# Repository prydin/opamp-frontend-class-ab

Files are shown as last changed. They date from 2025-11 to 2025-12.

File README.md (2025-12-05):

# The Teamwork Amplifier - 50W (8 ohm) Low Distortion Class AB Audio Amplifier

## Background
This is a team effort that started as a conversation on diyaudio.com. Member stigigemla and I were bouncing ideas back and forth and member steveu took one my design
attempts and came up with an overhauled and much improved version. I just added some extra features like overcurrent protecton and VI limiters and slapped together a PCB. 
I built it as an experiment.

The result is a fast amplifier (>80V/us slew rate) with low distortion (0.00045% meadured @ 1kHz/1W/8ohm resistive load). It's undergone some preliminary measurements
and looks quite promising. 

## Disclaimer
The schematic and PCB layout are free to use as you please, but bear in mind that it's only undergone a bare minimum of testing! Build at your own risk!

## Credits and acknowledgements
There were several people involved in the creation of this design. If you're not mentioned and feel you should be, just add your name and issue a PR! 

## Schematic
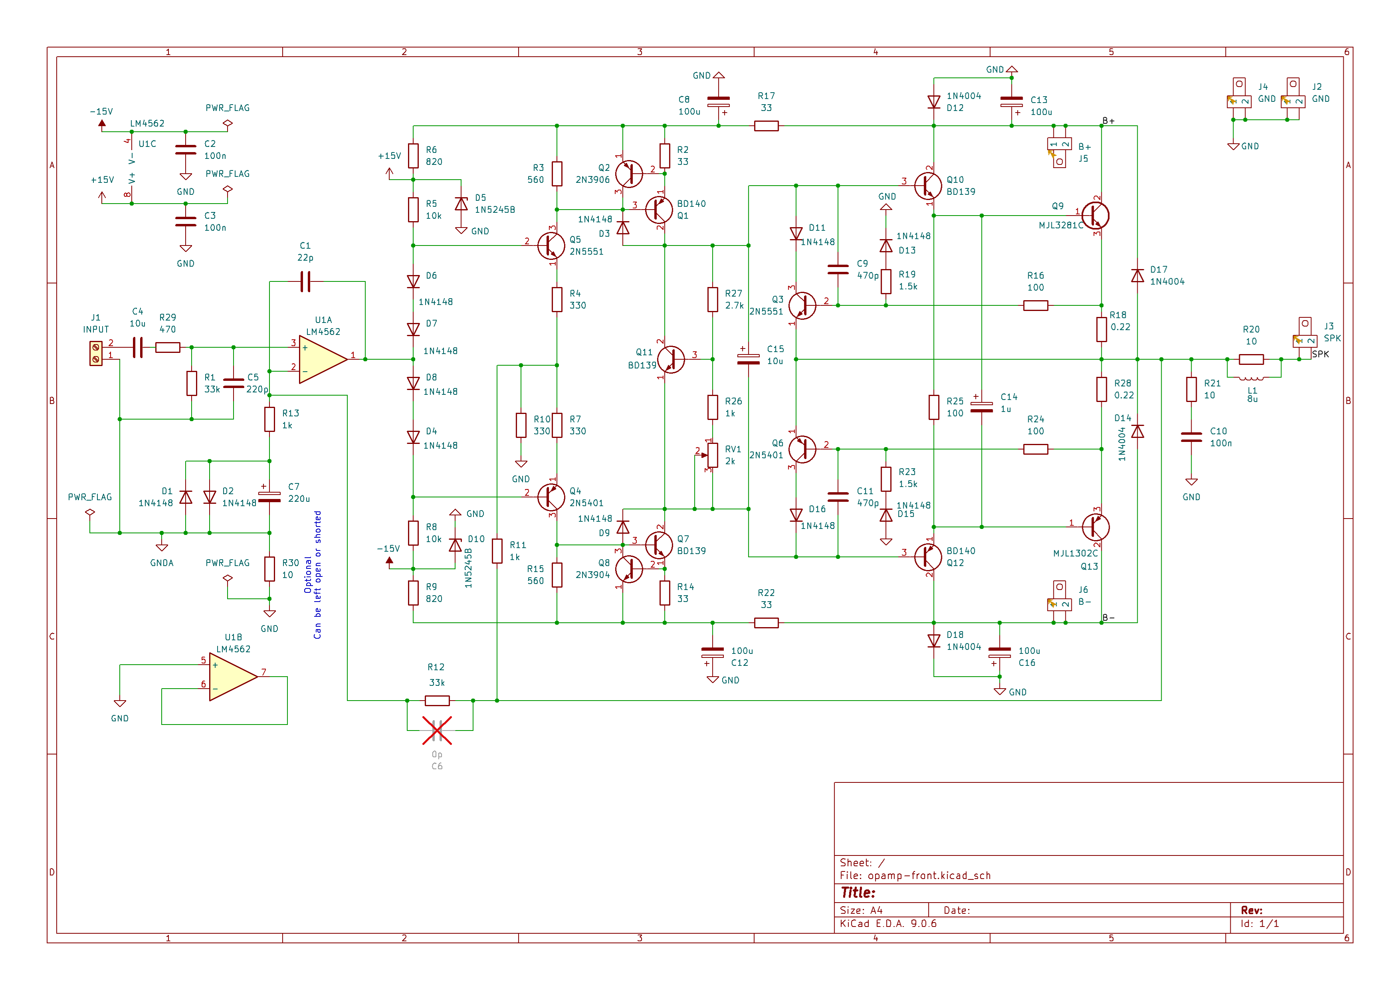
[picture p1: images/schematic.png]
Schematic


## PCB 3D rendering
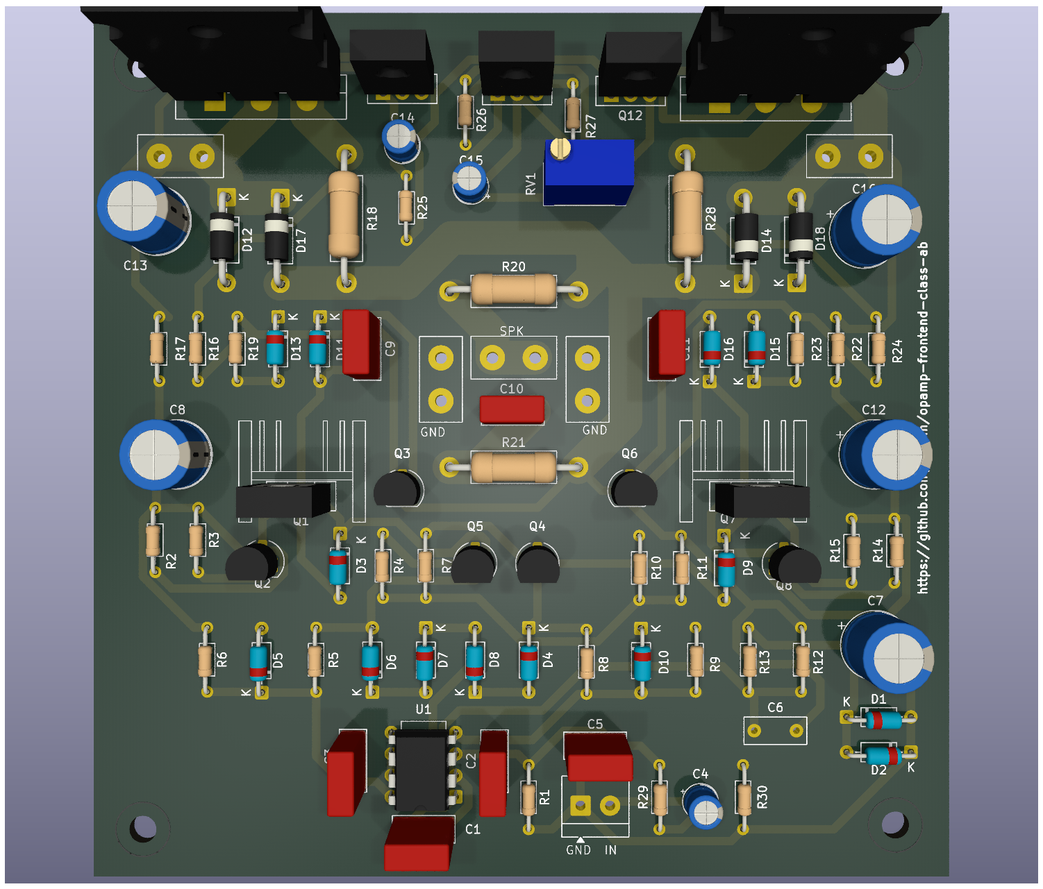
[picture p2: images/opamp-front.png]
PCB


## Measurements
- THD: 0.00045% @ 1W/1kHz/150mA bias
- SNR: >95dB
- Bandwidth: 10Hz-500kHz
- Slew rate: >80V/us

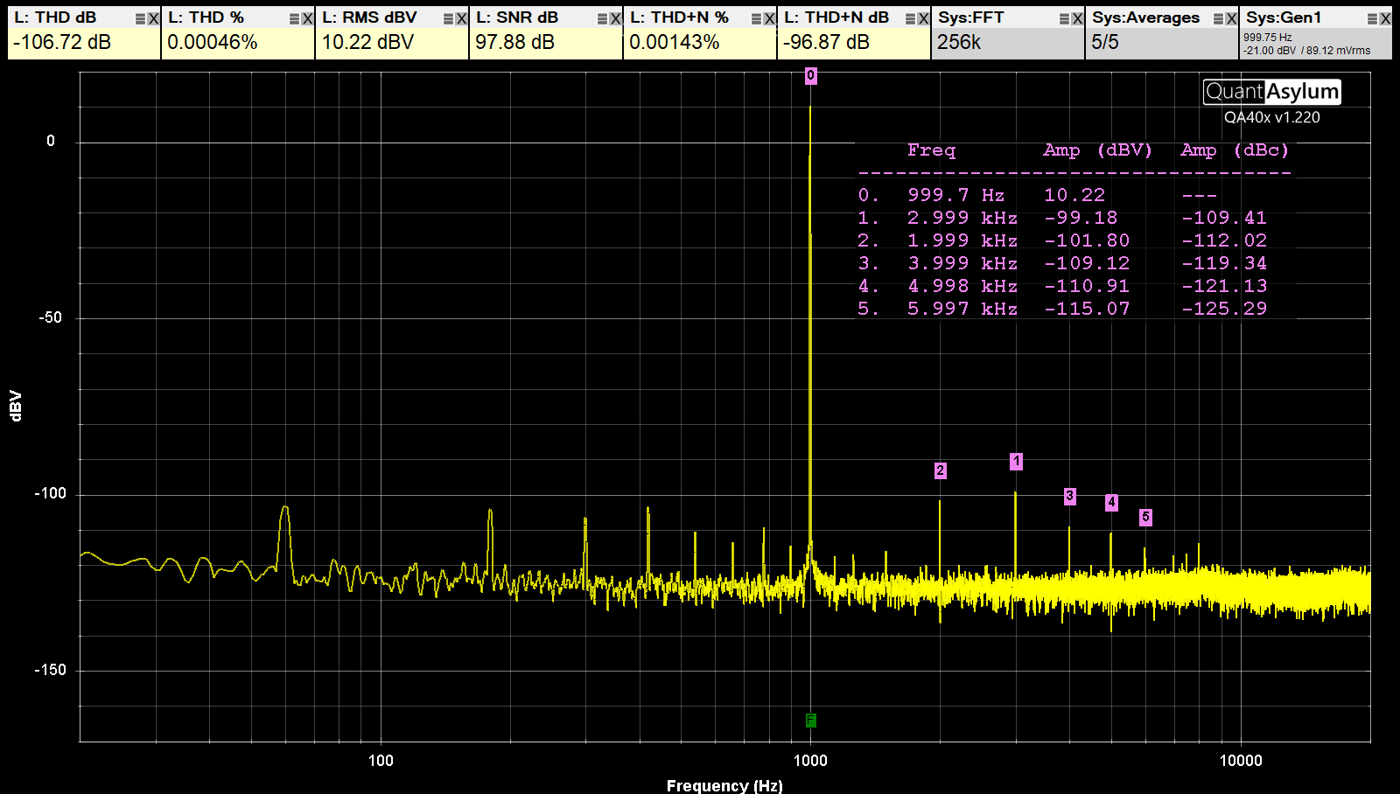
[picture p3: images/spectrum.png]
Spectrum


## Subjective listening impression
After a few hours of listening, I have to say I'm pleased with the sound quality. It character is very crisp and clean. Drum beats and cymbals feel very snappy. 
If you're looking for an amplifierthat colors the sound, this won't be your cup of tea. But so far I would say it does a great job at cleanly reproducing the source material. 

## Construction
I found an old, broken AudioSource Amp 100 on eBay for close to no money and reused the chassis, pots, connectors and transformer. The boards ended up fitting perfectly if
I moved the heatsink maybe 3mm back and removed the input switching board (which I didn't want or need anyway). It ended up being a neat and inexpensive build
that looks sleek and clean. 

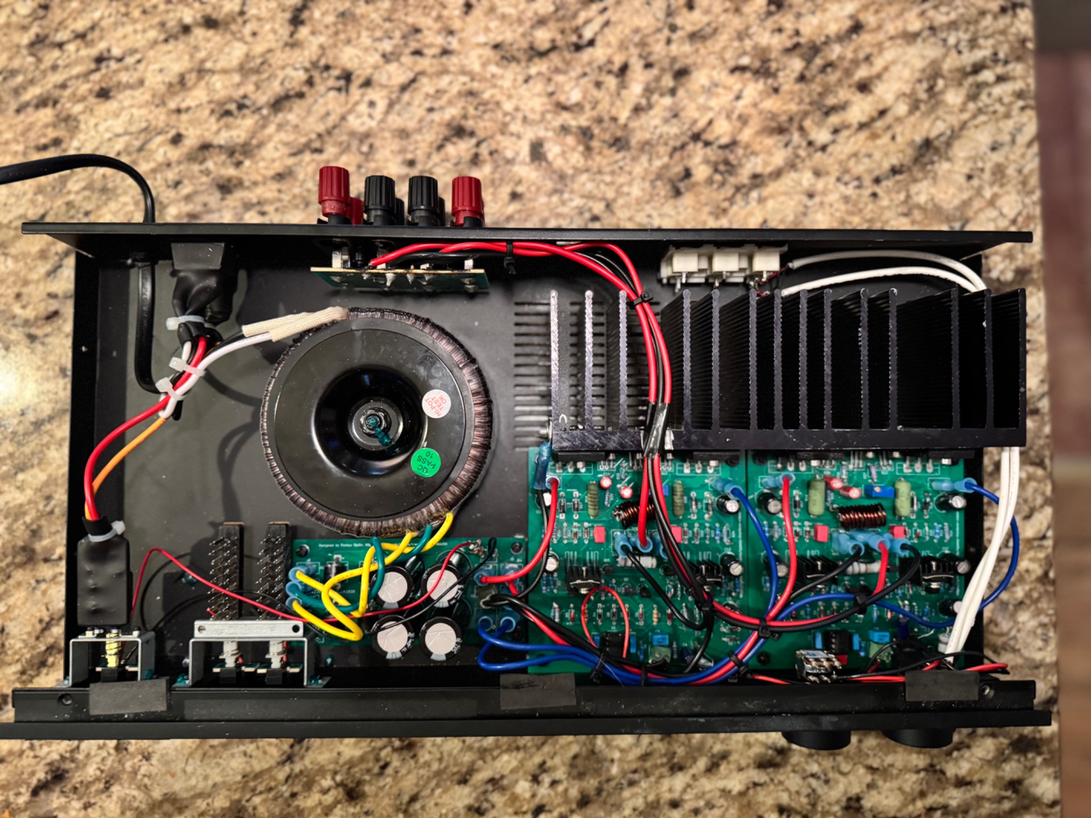
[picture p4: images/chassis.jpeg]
Build


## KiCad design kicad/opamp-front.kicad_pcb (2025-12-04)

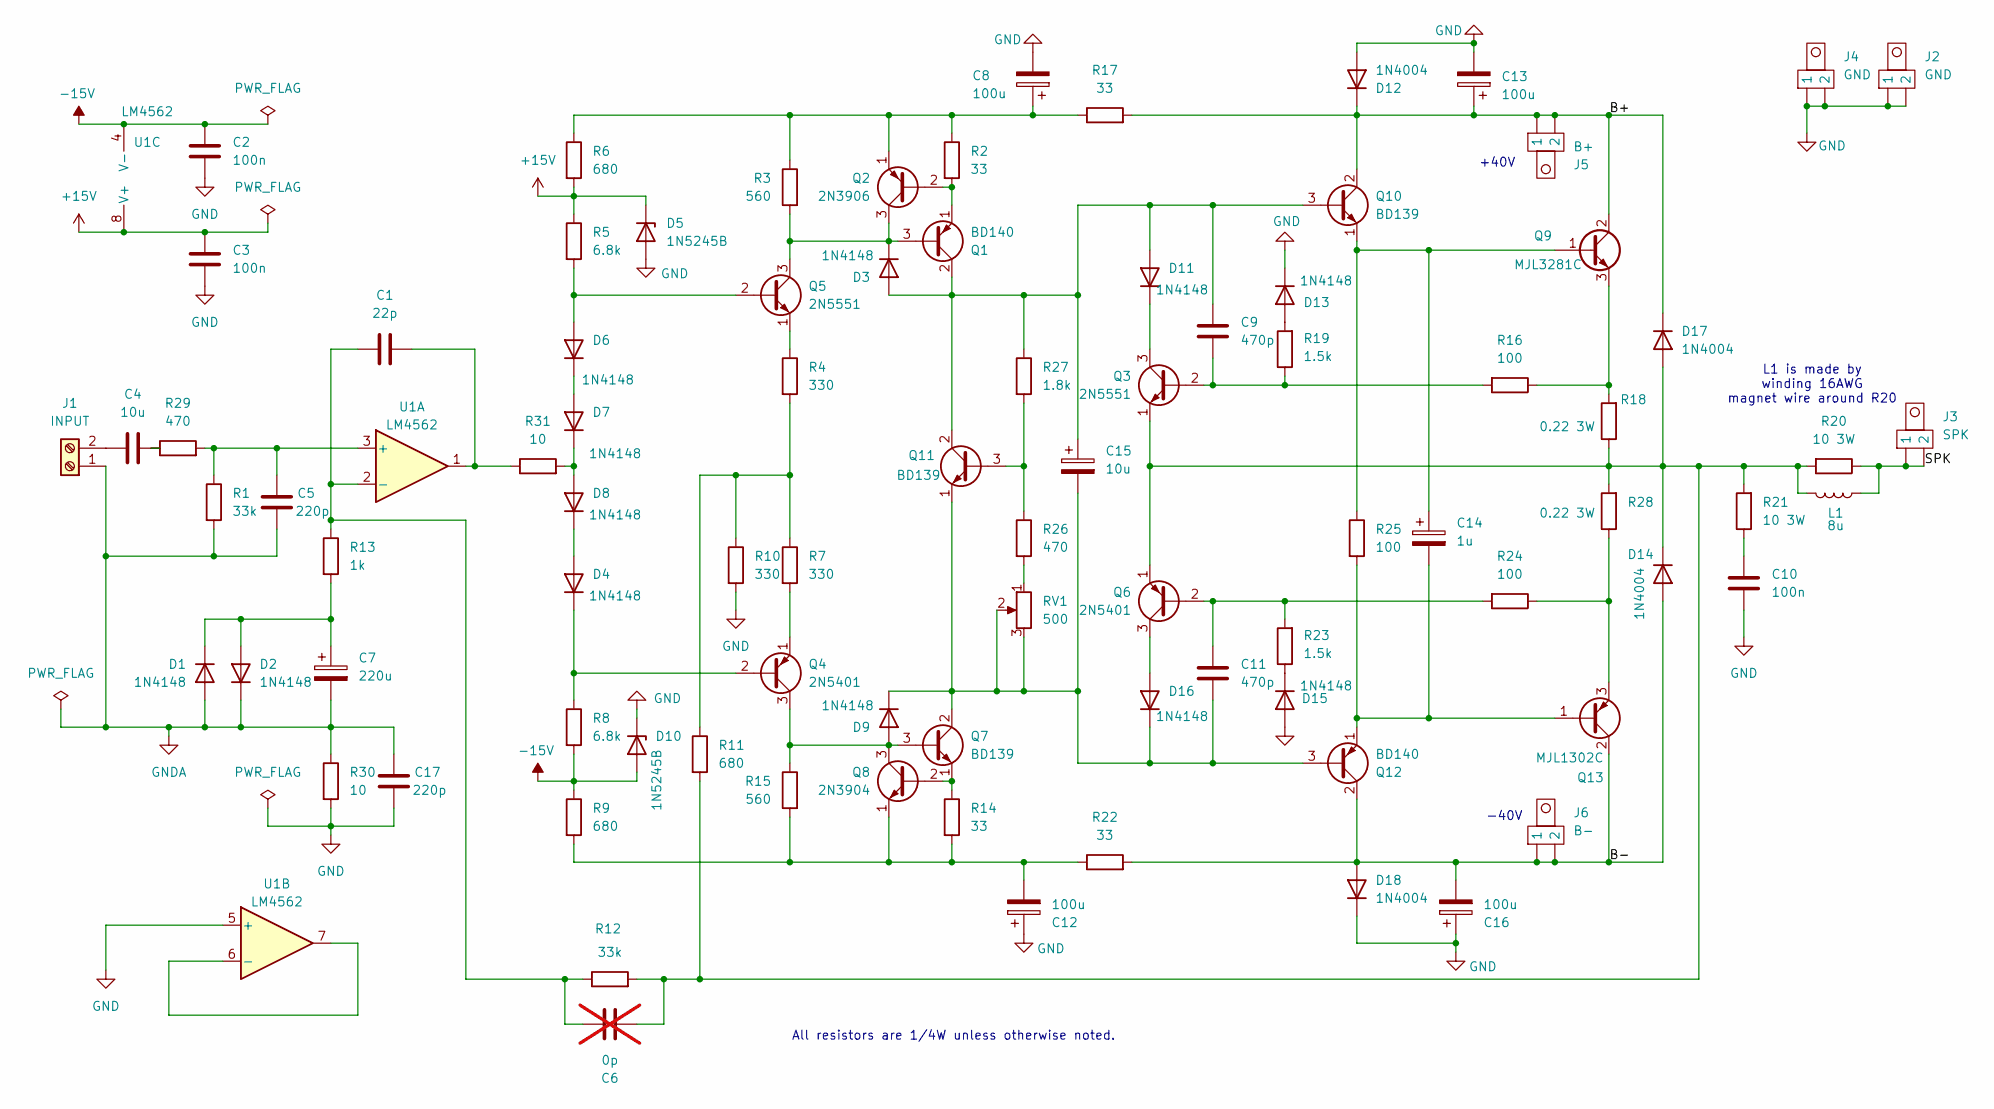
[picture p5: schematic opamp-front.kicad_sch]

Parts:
C1: 22p; C_Rect_L7.2mm_W3.0mm_P5.00mm_FKS2_FKP2_MKS2_MKP2
C2, C3, C10: 100n; C_Rect_L7.2mm_W3.0mm_P5.00mm_FKS2_FKP2_MKS2_MKP2
C4, C15: 10u; CP_Radial_D4.0mm_P2.00mm
C5, C17: 220p; C_Rect_L7.2mm_W3.0mm_P5.00mm_FKS2_FKP2_MKS2_MKP2
C6: 0p; C_Rect_L7.2mm_W3.0mm_P5.00mm_FKS2_FKP2_MKS2_MKP2; not fitted
C7: 220u; CP_Radial_D8.0mm_P5.00mm
C8, C12, C13, C16: 100u; CP_Radial_D8.0mm_P5.00mm
C9, C11: 470p; C_Rect_L7.2mm_W3.0mm_P5.00mm_FKS2_FKP2_MKS2_MKP2
C14: 1u; CP_Radial_D4.0mm_P2.00mm
D1, D2, D3, D4, D6, D7, D8, D9, D11, D13, D15, D16: 1N4148; D_DO-35_SOD27_P7.62mm_Horizontal
D5, D10: 1N5245B; D_DO-35_SOD27_P7.62mm_Horizontal
D12, D14, D17, D18: 1N4004; D_DO-41_SOD81_P10.16mm_Horizontal
J1: INPUT; TerminalBlock_4Ucon_1x02_P3.50mm_Horizontal
J2, J4: GND; Spade Connector
J3: SPK; Spade Connector
J5: B+; Spade Connector
J6: B-; Spade Connector
L1: 8u
Q1, Q12: BD140; TO-126-3_Vertical
Q2: 2N3906; TO-92_HandSolder
Q3, Q5: 2N5551; TO-92_HandSolder
Q4, Q6: 2N5401; TO-92_HandSolder
Q7, Q10, Q11: BD139; TO-126-3_Vertical
Q8: 2N3904; TO-92_HandSolder
Q9: MJL3281C; TO-264-3_Vertical
Q13: MJL1302C; TO-264-3_Vertical
R1, R12: 33k; R_Axial_DIN0204_L3.6mm_D1.6mm_P7.62mm_Horizontal_HandSolder
R2, R14, R17, R22: 33; R_Axial_DIN0204_L3.6mm_D1.6mm_P7.62mm_Horizontal_HandSolder
R3, R15: 560; R_Axial_DIN0204_L3.6mm_D1.6mm_P7.62mm_Horizontal_HandSolder
R4, R7, R10: 330; R_Axial_DIN0204_L3.6mm_D1.6mm_P7.62mm_Horizontal_HandSolder
R5, R8: 6.8k; R_Axial_DIN0204_L3.6mm_D1.6mm_P7.62mm_Horizontal_HandSolder
R6, R9, R11: 680; R_Axial_DIN0204_L3.6mm_D1.6mm_P7.62mm_Horizontal_HandSolder
R13: 1k; R_Axial_DIN0204_L3.6mm_D1.6mm_P7.62mm_Horizontal_HandSolder
R16, R24, R25: 100; R_Axial_DIN0204_L3.6mm_D1.6mm_P7.62mm_Horizontal_HandSolder
R18, R28: 0.22 3W; R_Axial_DIN0411_L9.9mm_D3.6mm_P15.24mm_Horizontal
R19, R23: 1.5k; R_Axial_DIN0204_L3.6mm_D1.6mm_P7.62mm_Horizontal_HandSolder
R20, R21: 10 3W; R_Axial_DIN0411_L9.9mm_D3.6mm_P15.24mm_Horizontal
R26, R29: 470; R_Axial_DIN0204_L3.6mm_D1.6mm_P7.62mm_Horizontal_HandSolder
R27: 1.8k; R_Axial_DIN0204_L3.6mm_D1.6mm_P7.62mm_Horizontal_HandSolder
R30, R31: 10; R_Axial_DIN0204_L3.6mm_D1.6mm_P7.62mm_Horizontal_HandSolder
RV1: 500; TRIM_T93YA103KT20
U1: LM4562; DIP-8_W7.62mm

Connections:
+15V: C3.2, D5.1 (K), R5.1, R6.2, U1.8 (V+)
-15V: C2.2, D10.2 (A), R8.2, R9.1, U1.4 (V-)
/B+: C13.1, D12.1 (K), D17.1 (K), J5.1, J5.2, Q9.2 (C), Q10.2 (C), R17.2
/B-: C16.2, D14.2 (A), D18.2 (A), J6.1, J6.2, Q12.2 (C), Q13.2 (C), R22.2
/SPK: J3.1, J3.2, L1.2, R20.1
GND: C2.1, C3.1, C8.2, C10.1, C12.1, C13.2, C16.1, C17.2, D5.2 (A), D10.1 (K), D12.2 (A), D13.1 (K), D15.2 (A), D18.1 (K), J2.1, J2.2, J4.1, J4.2, R10.2, R30.2, U1.5 (+)
GNDA: C5.2, C7.2, C17.1, D1.2 (A), D2.1 (K), J1.1, R1.2, R30.1
unnamed: C1.2, R31.1, U1.1
unnamed: C4.2, R29.1
unnamed: C10.2, R21.1
unnamed: C7.1, D1.1 (K), D2.2 (A), R13.2
unnamed: D3.1 (K), Q1.3 (B), Q2.3 (C), Q5.3 (C), R3.2
unnamed: D4.2 (A), D8.1 (K)
unnamed: D4.1 (K), Q4.2 (B), R8.1
unnamed: D6.2 (A), Q5.2 (B), R5.2
unnamed: D6.1 (K), D7.2 (A)
unnamed: D7.1 (K), D8.2 (A), R31.2
unnamed: D9.2 (A), Q4.3 (C), Q7.3 (B), Q8.3 (C), R15.1
unnamed: C9.2, C15.1, D3.2 (A), D11.2 (A), Q1.2 (C), Q10.3 (B), Q11.2 (C), R27.1
unnamed: D11.1 (K), Q3.3 (C)
unnamed: D13.2 (A), R19.2
unnamed: C6.2, D14.1 (K), D17.2 (A), L1.1, Q3.1 (E), Q6.1 (E), R11.2, R12.2, R18.1, R20.2, R21.2, R28.2
unnamed: D15.1 (K), R23.1
unnamed: D16.2 (A), Q6.3 (C)
unnamed: C11.1, C15.2, D9.1 (K), D16.1 (K), Q7.2 (C), Q11.1 (E), Q12.3 (B), RV1.2, RV1.3
unnamed: C4.1, J1.2
unnamed: Q1.1 (E), Q2.2 (B), R2.2
unnamed: C8.1, Q2.1 (E), R2.1, R3.1, R6.1, R17.1
unnamed: C9.1, Q3.2 (B), R16.2, R19.1
unnamed: Q4.1 (E), R7.2
unnamed: Q5.1 (E), R4.1
unnamed: C11.2, Q6.2 (B), R23.2, R24.2
unnamed: Q7.1 (E), Q8.2 (B), R14.1
unnamed: C12.2, Q8.1 (E), R9.2, R14.2, R15.2, R22.1
unnamed: Q9.3 (E), R16.1, R18.2
unnamed: C14.1, Q9.1 (B), Q10.1 (E), R25.1
unnamed: Q11.3 (B), R26.1, R27.2
unnamed: C14.2, Q12.1 (E), Q13.1 (B), R25.2
unnamed: Q13.3 (E), R24.1, R28.1
unnamed: R4.2, R7.1, R10.1, R11.1
unnamed: R26.2, RV1.1
unnamed: C5.1, R1.1, R29.2, U1.3 (+)
unnamed: C1.1, C6.1, R12.1, R13.1, U1.2 (-)
unnamed: U1.6 (-), U1.7

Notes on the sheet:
-40V
+40V
L1 is made by winding 16AWG magnet wire around R20
All resistors are 1/4W unless otherwise noted.

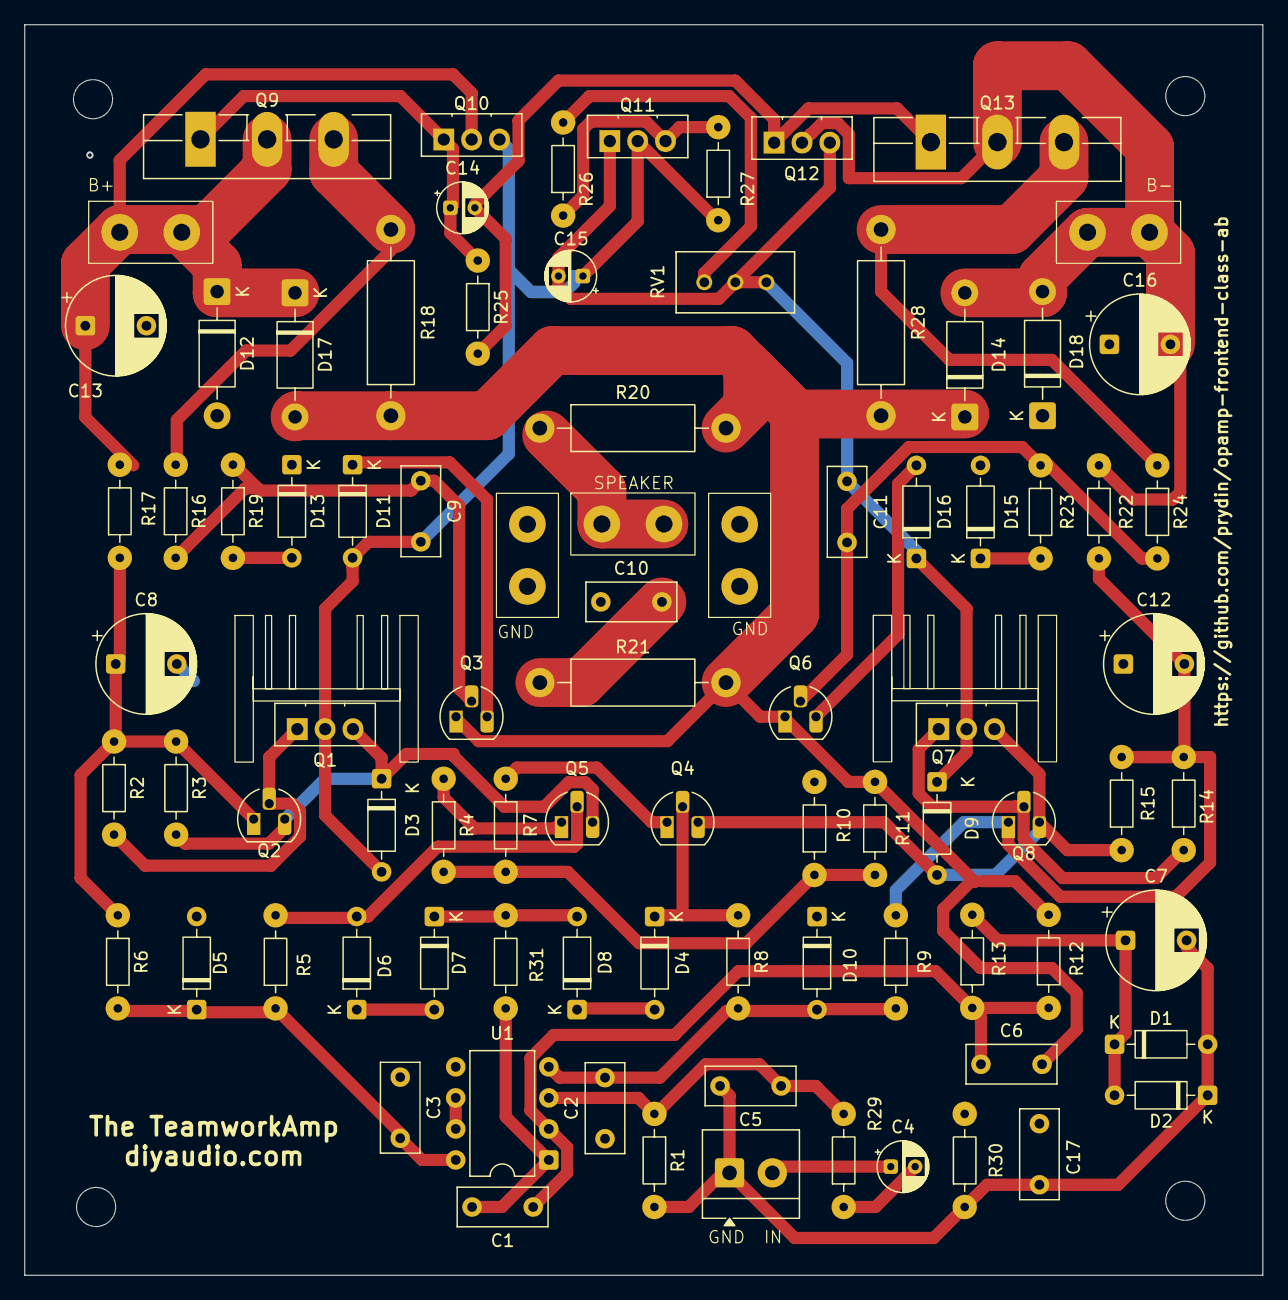
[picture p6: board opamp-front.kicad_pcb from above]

Board: 2 copper layers, 101.3 x 102.4 mm, 87 parts (0 on the bottom side), 44 nets.

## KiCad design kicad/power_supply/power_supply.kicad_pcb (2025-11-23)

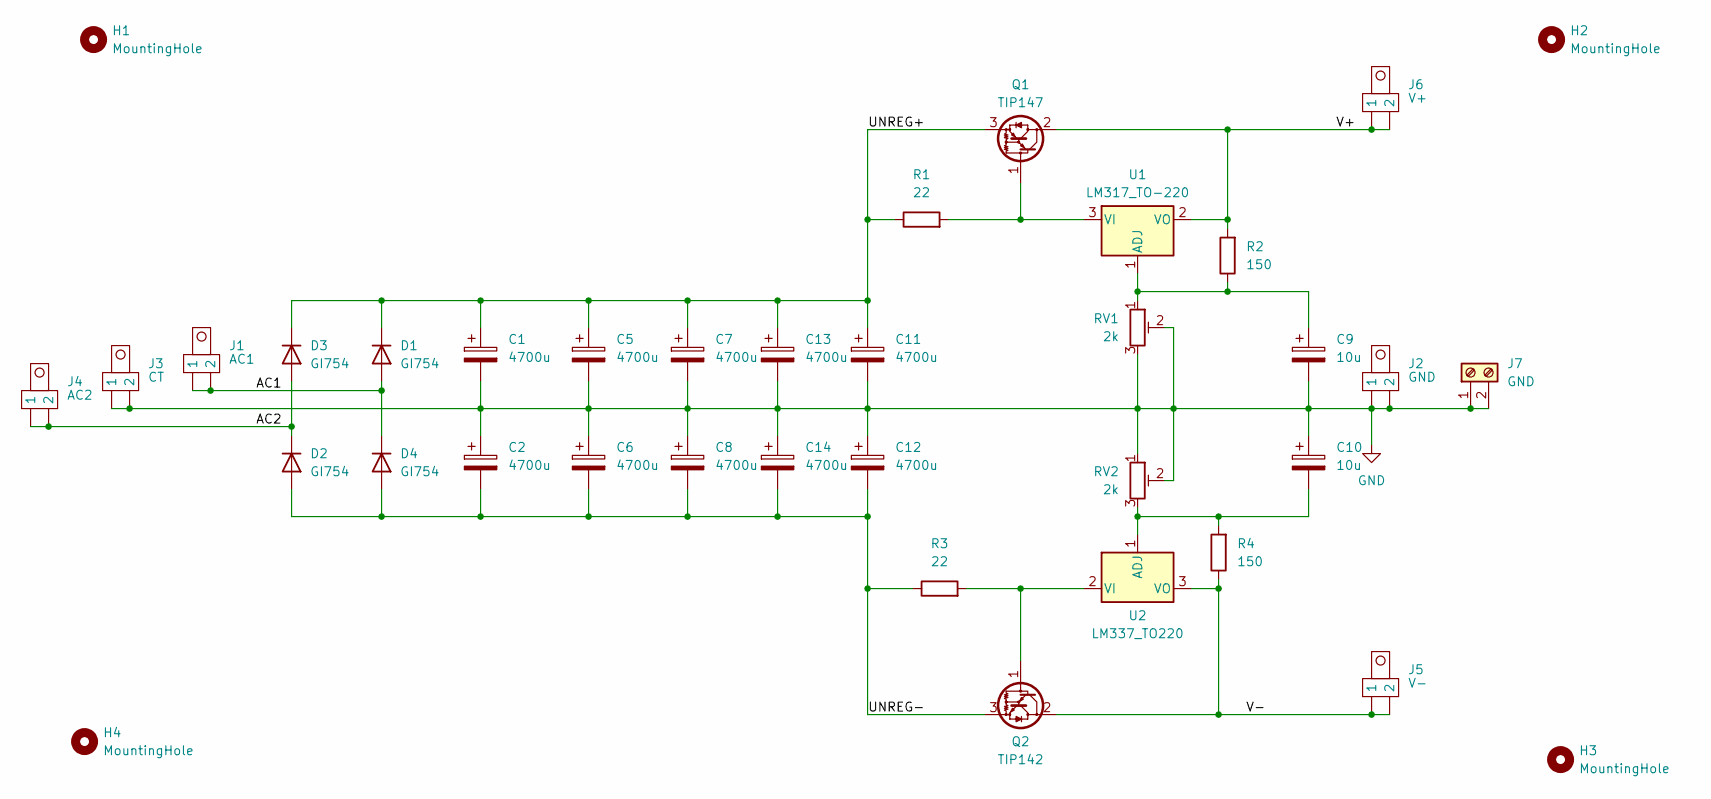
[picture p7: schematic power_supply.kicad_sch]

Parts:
C1, C2, C5, C6, C7, C8, C11, C12, C13, C14: 4700u; CP_Radial_D18.0mm_P7.50mm
C9, C10: 10u; CP_Radial_D4.0mm_P2.00mm
D1, D2, D3, D4: GI754; D_P600_R-6_P12.70mm_Horizontal
H1, H2, H3, H4: MountingHole; MountingHole_3.2mm_M3
J1: AC1; Spade Connector
J2: GND; Spade Connector
J3: CT; Spade Connector
J4: AC2; Spade Connector
J5: V-; Spade Connector
J6: V+; Spade Connector
J7: GND; TerminalBlock_Phoenix_MKDS-1,5-2_1x02_P5.00mm_Horizontal
Q1: TIP147; TO-247-3_Horizontal_TabDown
Q2: TIP142; TO-247-3_Horizontal_TabDown
R1, R3: 22; R_Axial_DIN0204_L3.6mm_D1.6mm_P7.62mm_Horizontal
R2, R4: 150; R_Axial_DIN0204_L3.6mm_D1.6mm_P7.62mm_Horizontal
RV1, RV2: 2k; TRIM_T93YA103KT20
U1: LM317_TO-220; TO-220-3_Vertical
U2: LM337_TO220; TO-220-3_Vertical

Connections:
/AC1: D1.2 (A), D4.1 (K), J1.1, J1.2
/AC2: D2.1 (K), D3.2 (A), J4.1, J4.2
/UNREG+: C1.1, C5.1, C7.1, C11.1, C13.1, D1.1 (K), D3.1 (K), Q1.3 (E), R1.1
/UNREG-: C2.2, C6.2, C8.2, C12.2, C14.2, D2.2 (A), D4.2 (A), Q2.3 (E), R3.1
/V+: J6.1, J6.2, Q1.2 (C), R2.2, U1.2 (VO); also elsewhere on the board
/V-: J5.1, J5.2, Q2.2 (C), R4.1, U2.3 (VO); also elsewhere on the board
GND: C1.2, C2.1, C5.2, C6.1, C7.2, C8.1, C9.2, C10.1, C11.2, C12.1, C13.2, C14.1, J2.1, J2.2, J3.1, J3.2, J7.1, J7.2, RV1.2, RV1.3, RV2.1, RV2.2; also elsewhere on the board
unnamed: Q1.1 (B), R1.2, U1.3 (VI)
unnamed: Q2.1 (B), R3.2, U2.2 (VI)
unnamed: C9.1, R2.1, RV1.1, U1.1 (ADJ)
unnamed: C10.2, R4.2, RV2.3, U2.1 (ADJ)

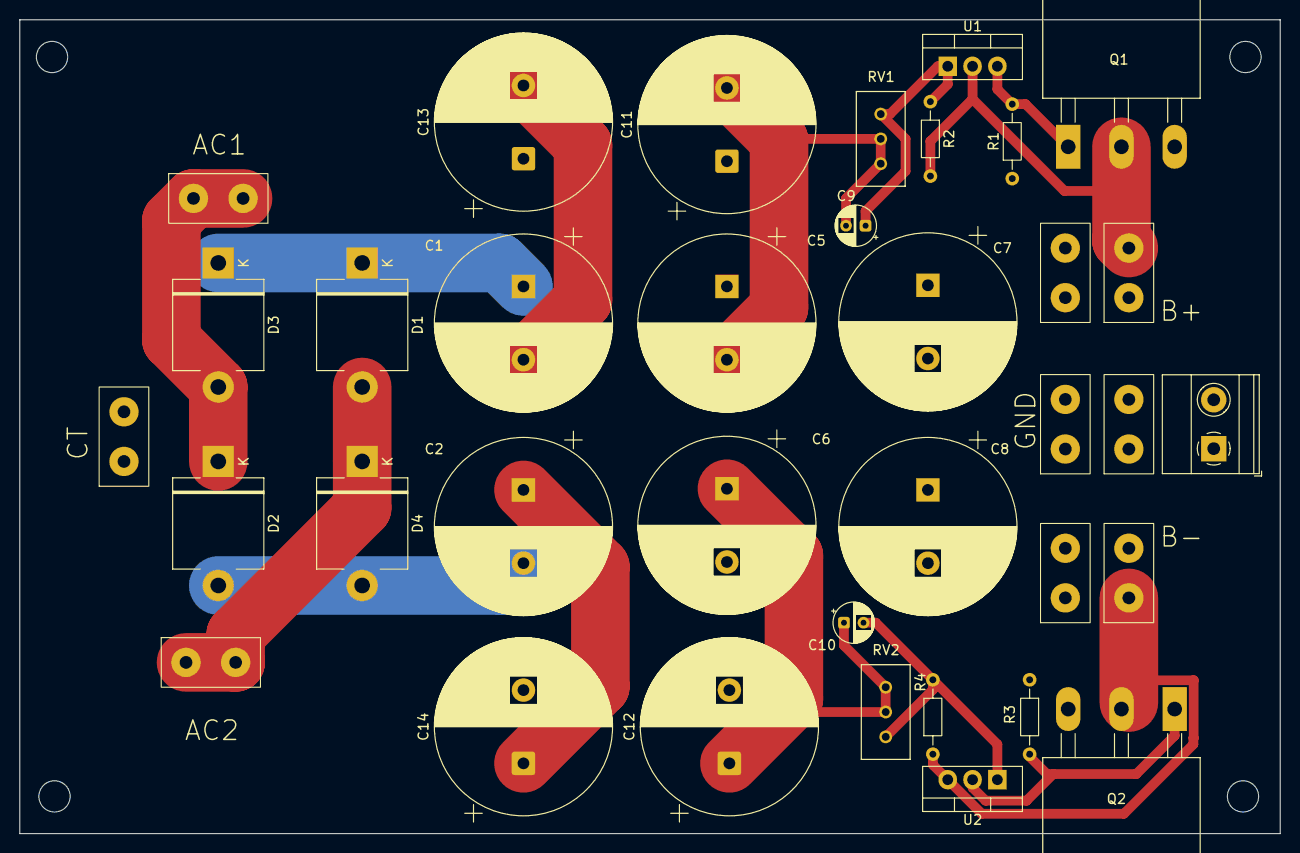
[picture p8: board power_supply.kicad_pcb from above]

Board: 2 copper layers, 129.0 x 83.3 mm, 40 parts (0 on the bottom side), 11 nets.

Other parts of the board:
J3#2: CT; Spade Connector
J5#2: V-; Spade Connector
J6#2: V+; Spade Connector

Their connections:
/V+: J6#2.1, J6#2.2; also elsewhere on the board
/V-: J5#2.1, J5#2.2; also elsewhere on the board
GND: J3#2.1, J3#2.2; also elsewhere on the board

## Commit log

2025-11-13 Gerbers generated
    [opamp-front-B_Cu.gbr, opamp-front-B_Mask.gbr, opamp-front-B_Paste.gbr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]
2025-11-23 Preparing for public release
    [opamp-front-B_Cu.gbr, opamp-front-B_Mask.gbr, opamp-front-B_Paste.gbr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]
2025-11-23 Restored after rebase mishap
    [opamp-front.kicad_pcb, opamp-front.kicad_sch]
2025-11-24 Release 1.0
    [opamp-front-B_Cu.gbr, opamp-front-B_Mask.gbr, opamp-front-B_Paste.gbr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]
2025-11-24 Cleaned up
    [opamp-front.kicad_pcb, opamp-front.kicad_sch]
2025-11-27 PCB improvments and lineup's adjustments.
    [opamp-front-B_Cu.gbr, opamp-front-B_Mask.gbr, opamp-front-B_Paste.gbr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]
2025-11-27 Cosmetic adjustments
    [opamp-front-B_Cu.gbr, opamp-front-B_Mask.gbr, opamp-front-B_Paste.gbr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]
2025-12-04 Release candidate 1
    [opamp-front.kicad_pcb, opamp-front.kicad_sch]
